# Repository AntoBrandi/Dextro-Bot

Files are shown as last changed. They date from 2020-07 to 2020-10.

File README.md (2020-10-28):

<!-- PROJECT SHIELDS -->
<!--
*** I'm using markdown "reference style" links for readability.
*** Reference links are enclosed in brackets [ ] instead of parentheses ( ).
*** See the bottom of this document for the declaration of the reference variables
*** for contributors-url, forks-url, etc. This is an optional, concise syntax you may use.
*** https://www.markdownguide.org/basic-syntax/#reference-style-links
-->
[][linkedin-url]

<!-- PROJECT LOGO -->
<br />
<p align="center">
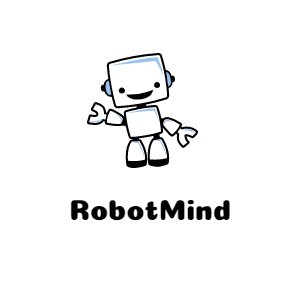
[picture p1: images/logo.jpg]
   

  <h3 align="center">DextroBot</h3>

  <p align="center">
    3D printed omni-directional robot with mechanum wheel powered by ROS
    <br />
    <a href="https://github.com/AntoBrandi/DextroBot/"><strong>Explore the docs »</strong></a>
    <br />
    <br />
    <a href="https://github.com/AntoBrandi/DextroBot/">View Demo</a>
    ·
    <a href="https://github.com/AntoBrandi/DextroBot/issues">Report Bug</a>
    ·
    <a href="https://github.com/AntoBrandi/DextroBot/issues">Request Feature</a>
  </p>
</p>

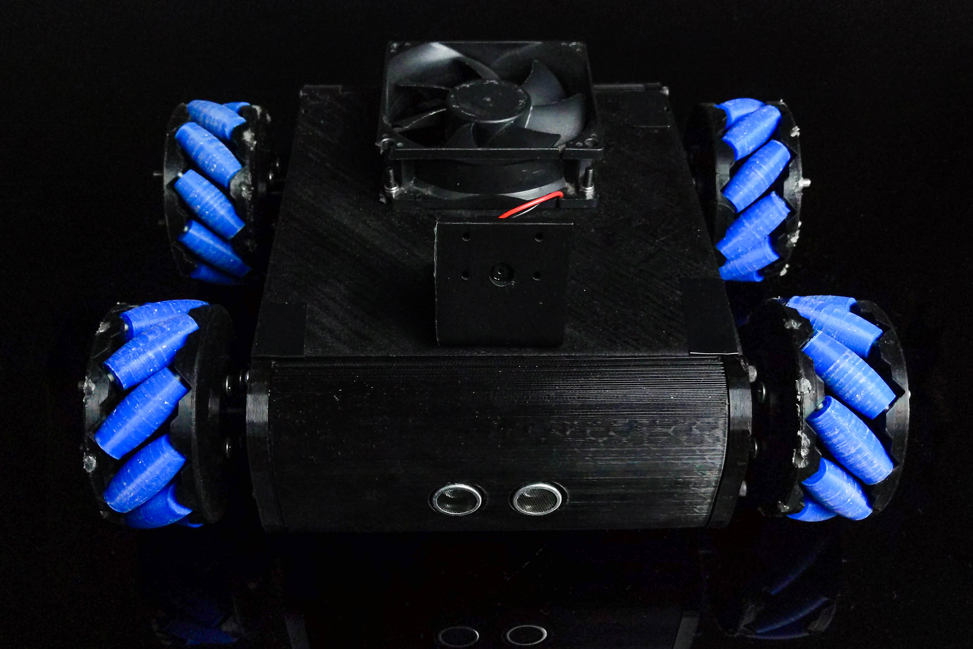
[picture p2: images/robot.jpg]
Product Name Screen Shot Real
[](https://example.com)

<!-- TABLE OF CONTENTS -->
## Table of Contents

* [About the Project](#about-the-project)
  * [Built With](#built-with)
* [Getting Started](#getting-started)
  * [Prerequisites](#prerequisites)
  * [Installation](#installation)
* [Usage](#usage)
* [Contributing](#contributing)
* [License](#license)
* [Contact](#contact)
* [Acknowledgements](#acknowledgements)

<!-- ABOUT THE PROJECT -->
## About The Project

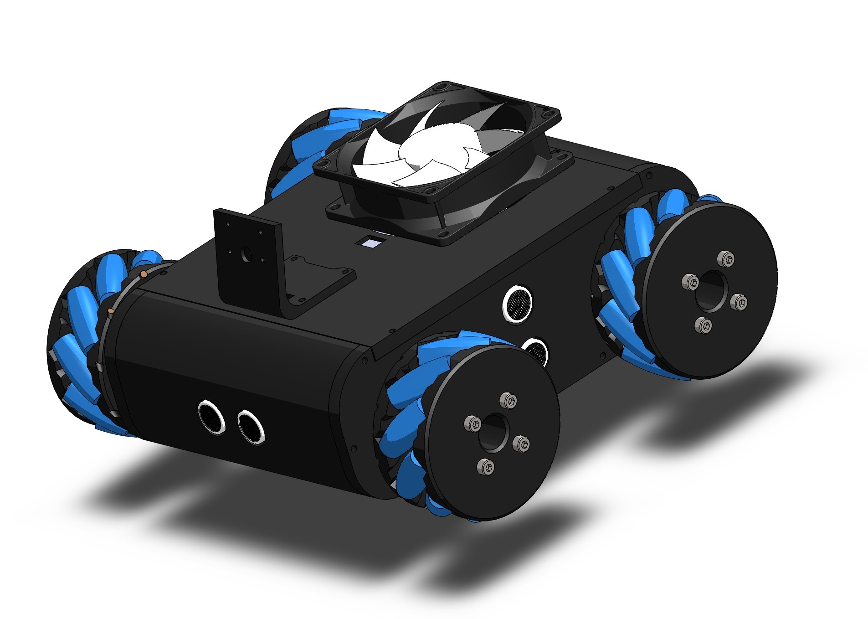
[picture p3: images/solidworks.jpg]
Product Name Screen Shot
[](https://example.com)

This project aim is to build an omni-directional robot for the indoor navigation and mapping using inexpensive sensors such as ultrasonic sensors.
Furthermore, it implements some basics human tracking and following functionalities using the raspberry pi camera mounted on its top. In order to activate or deactivate
this tracking functionalities, a speech recognition module has been implemented. This module can run on any computer with a microphone that is connected to the same Wi-Fi network 
of the robot.

### Built With
This robot is powered by:
* Raspberry Pi 4
* Arduino UNO
* CNC Shield
* Nema 17 Stepper Motor
* drv8825 Stepper Motor Driver
* 11.1V 3s LiPo Battery
* LM2596 DC-DC converter
* Raspberry Pi Camera
* HC-SR04 Ultrasonic Sensors
* MPU6050 IMU

And is controlled by:
* ROS Kinetic

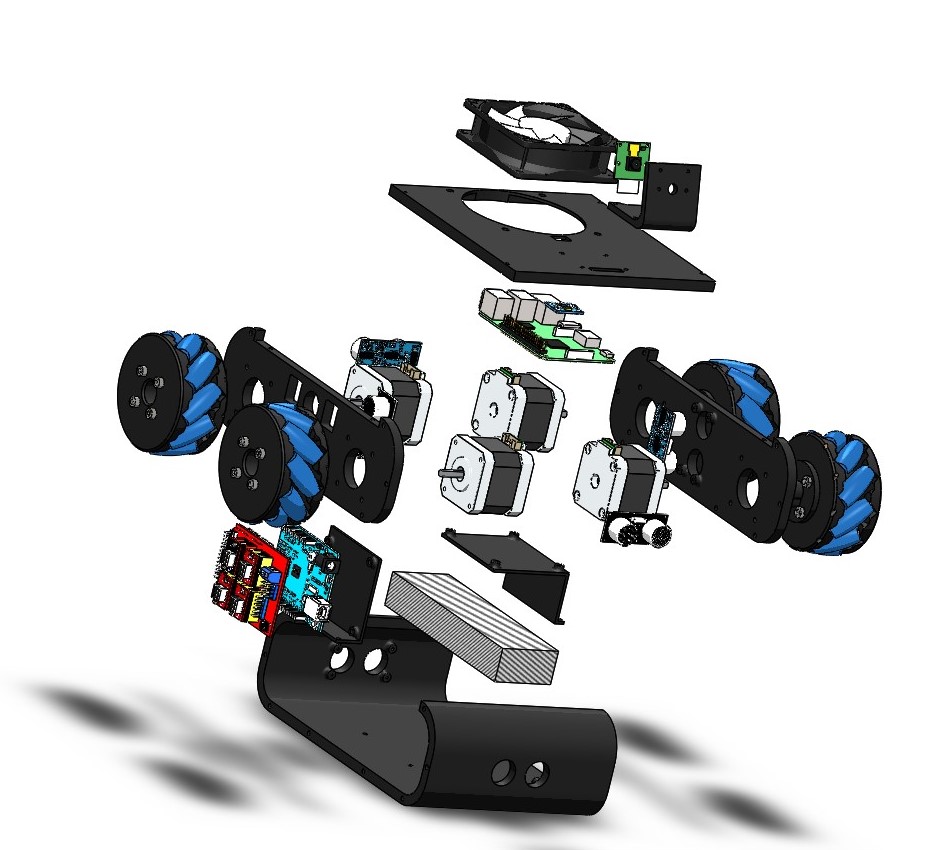
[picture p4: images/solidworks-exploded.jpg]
Product Name Screen Shot Exploded
[](https://example.com)

<!-- GETTING STARTED -->
## Getting Started

Once it's printed and assembled according and connected, there are few configuration to be made in both Raspberry Pi side and Arduino UNO.

### Prerequisites

Make sure you install correctly the following required tools before continuing
* Install Ubuntu 16.04 on Raspberry Pi 4
Use the [Ubiquity Robotics](https://downloads.ubiquityrobotics.com/pi.html) Raspberry Pi images that cames along with a lot of pre-installed functionalities such as ROS kinetic, ssh server, GPIO and camera
drivers
* Install missing ROS libraries. Some libraries that are used in this project are not in the standard ROS package. Install them with:
```sh
sudo apt-get install ros-kinetic-rosserial
```
```sh
sudo apt-get install ros-kinetic-rosserial-arduino
```
```sh
sudo apt-get install ros-kinetic-rviz-imu-plugin
```
* Install VS Code and Platform IO extension on your PC in order to build and load the Arduino code on the device

### Installation

1. Clone the repo
```sh
git clone https://github.com/AntoBrandi/DextroBot.git
```
2. Build the ROS workspace
```sh
cd ~/DextroBot/ROS/dextrobot_ws
```
```sh
catkin_make
```
3. Source the project
```sh
sudo nano ~/.bashrc
```
And add the following at the end of the document
```sh
source ~/DextroBot/ROS/dextrobot_ws/devel/setup.bash
```
4. Connect the Arduino UNO on your PC with VS Code and Platform IO. Open the [folder](https://github.com/AntoBrandi/DextroBot/tree/master/ROS/dextrobot_ws/src/dextrobot_controller/src/arduino/wheel_controller)
containing the code for the Arduino wheel control and load the main.cpp to the Arduino.

<!-- USAGE EXAMPLES -->
## Usage

To launch the ROS enviroment on the Raspberry Pi use
```sh
roslaunch dextrobot_bringup dextrobot_complete.launch view_imv:=true
```
With optional parameters
* **view_imv**: to display the motion vectors detected by the raspberry pi camera
* **launch_rviz**: to display the readings coming from the sonar sensors and the imu

<!-- CONTRIBUTING -->
## Contributing

Contributions are what make the open source community such an amazing place to be learn, inspire, and create. Any contributions you make are **greatly appreciated**.

1. Fork the Project
2. Create your Feature Branch (`git checkout -b feature/AmazingFeature`)
3. Commit your Changes (`git commit -m 'Add some AmazingFeature'`)
4. Push to the Branch (`git push origin feature/AmazingFeature`)
5. Open a Pull Request

<!-- LICENSE -->
## License

Distributed under the MIT License. See `LICENSE` for more information.

<!-- CONTACT -->
## Contact

Antonio Brandi - [LinkedIn]([linkedin-url]) - antonio.brandi@outlook.it

My Projects: [https://github.com/AntoBrandi](https://github.com/AntoBrandi)

<!-- ACKNOWLEDGEMENTS -->
## Acknowledgements
* [Ubiquity Robotics Raspberry Pi Images](https://downloads.ubiquityrobotics.com/pi.html)
* [Ubiquity Robotics raspicam_node](https://github.com/UbiquityRobotics/raspicam_node)
* [How To Mechatronics mechanum wheel](https://howtomechatronics.com/)

<!-- MARKDOWN LINKS & IMAGES -->
<!-- https://www.markdownguide.org/basic-syntax/#reference-style-links -->
[linkedin-shield]: https://img.shields.io/badge/-LinkedIn-black.svg?style=flat-square&logo=linkedin&colorB=555
[linkedin-url]: https://www.linkedin.com/in/antonio-brandi-512166bb/
[product-screenshot]: images/solidworks.jpg
[product-screenshot-exploded]: images/solidworks-exploded.jpg
[product-screenshot-real]: images/robot.jpg

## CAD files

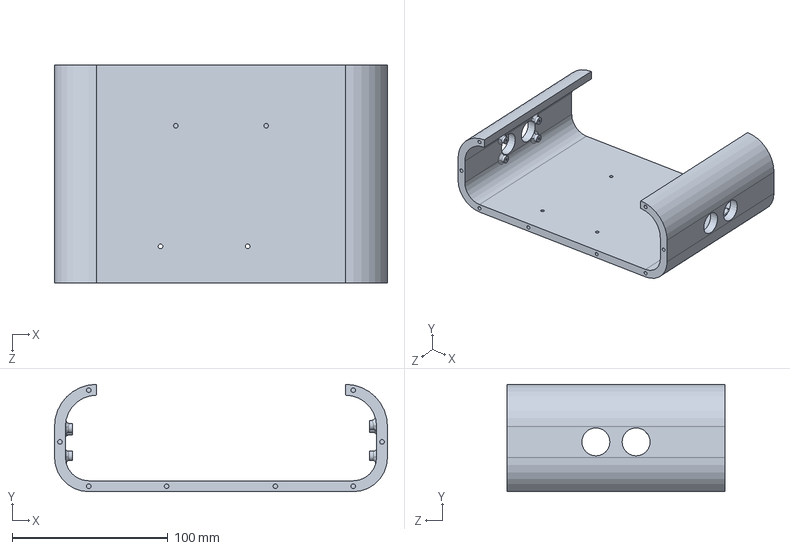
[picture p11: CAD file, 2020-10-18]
CAD/rev_2/carena_main.SLDPRT
214.0 x 69.0 x 140.0 mm

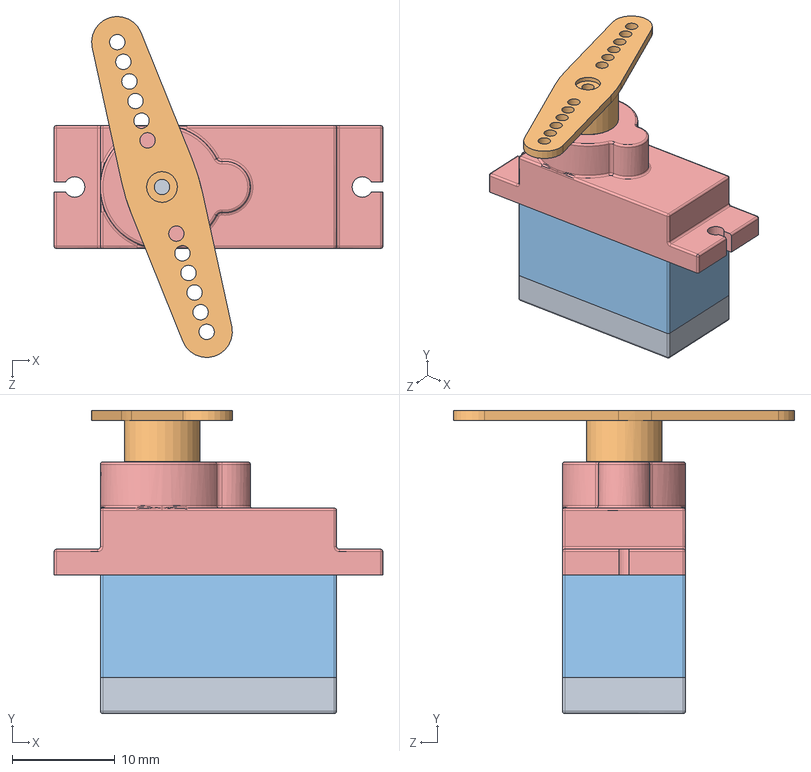
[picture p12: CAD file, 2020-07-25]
CAD/Servo/servo.SLDASM
32.0 x 29.5 x 33.2 mm
bottom
Driver
middle
screw x 4
top

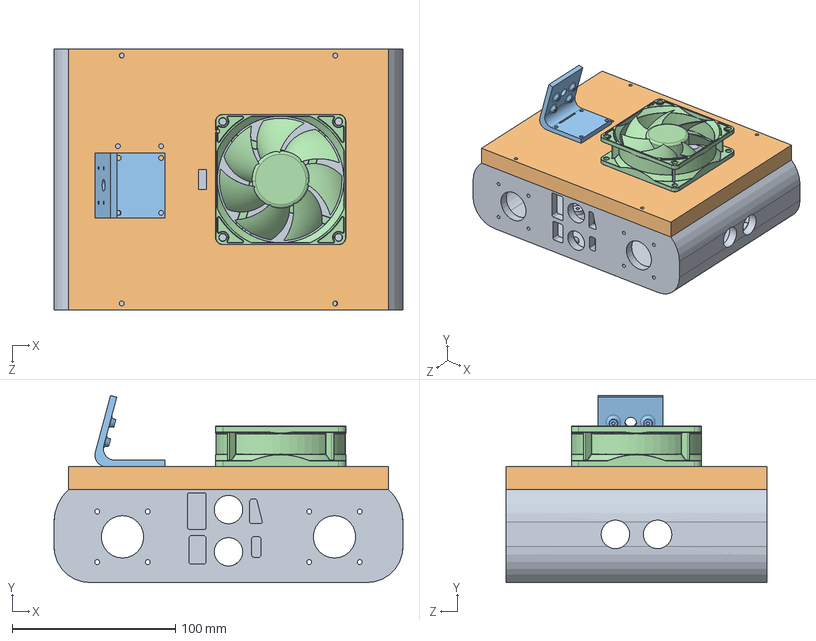
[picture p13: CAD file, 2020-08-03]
CAD/structure.SLDASM
214.0 x 114.7 x 160.0 mm
carena
carena_top_3
Camera Stand
80mm fan

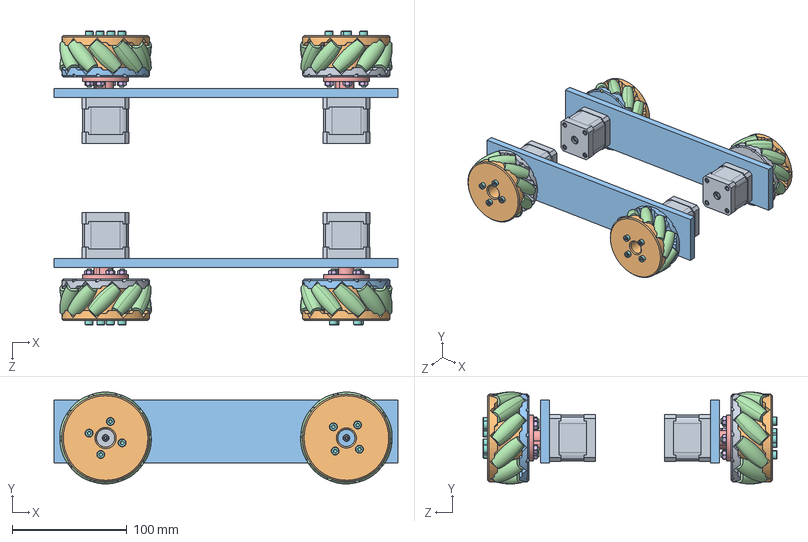
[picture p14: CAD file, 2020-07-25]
CAD/DextroBot.SLDASM
300.0 x 80.2 x 256.3 mm
NEMA 17 34mm_Varsayilan x 4
Wheel outer side Left x 2
Wheel base plate 1 Left x 2
Roller 3 x 40
Shaft Coupler Nema 17 x 4
hex nut style 1 gradeab_din_Hexagon Nut ISO 4032 - M4 - W - N x 16
Roller Shaft x 40
socket head cap screw_am_B18.3.1M - 4 x 0.7 x 45 Hex SHCS -- 20NHX x 16
Wheel base plate 1 Right x 2
Wheel outer side Right x 2
Base side plate x 2

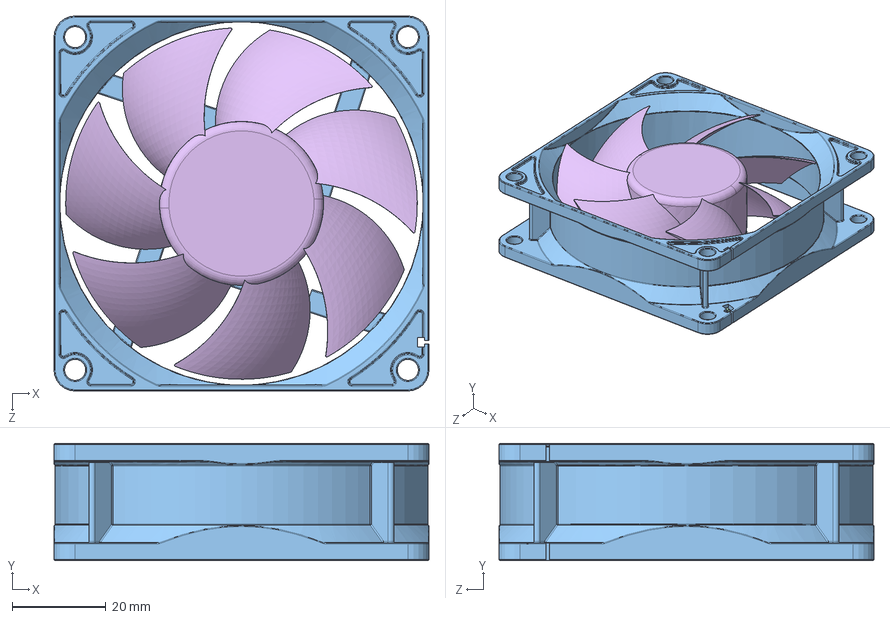
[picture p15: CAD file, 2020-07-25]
CAD/Electronics/80mm fan.SLDASM
80.0 x 25.0 x 80.0 mm
agfan
agfan-1
agfan-2
agfan-3
agfan-4
blade

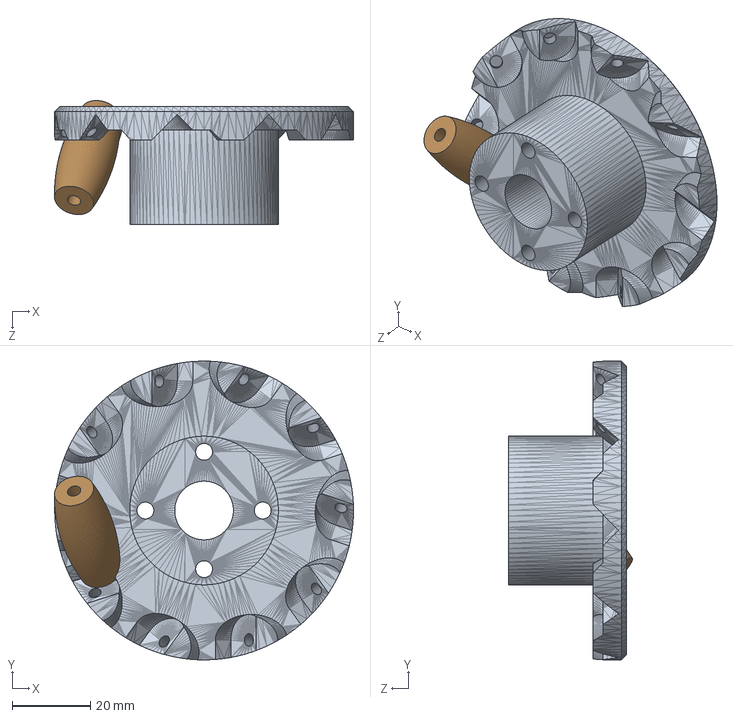
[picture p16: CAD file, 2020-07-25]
CAD/left_wheel.SLDASM
76.4 x 76.4 x 31.7 mm
Wheel outer side Left
Roller

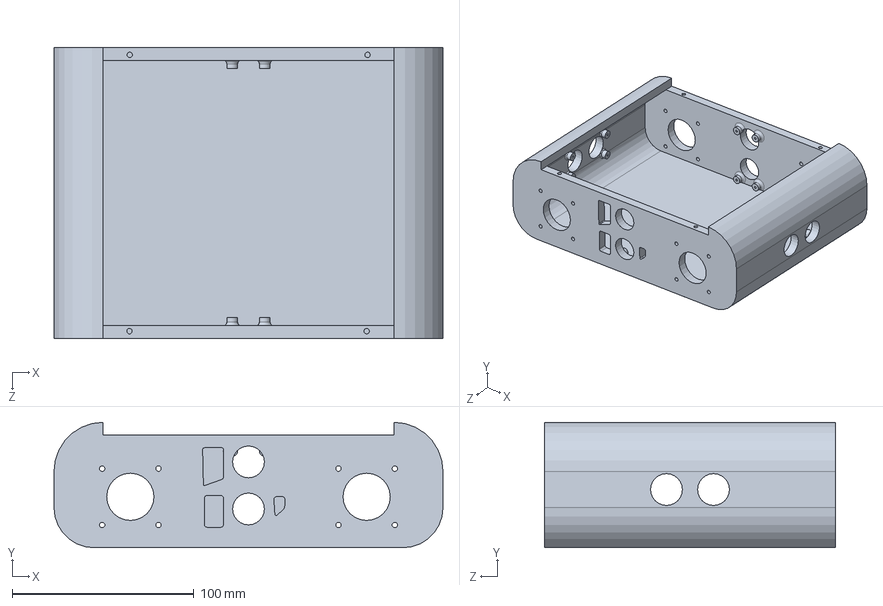
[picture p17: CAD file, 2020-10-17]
CAD/carena.SLDPRT
214.0 x 69.0 x 160.0 mm

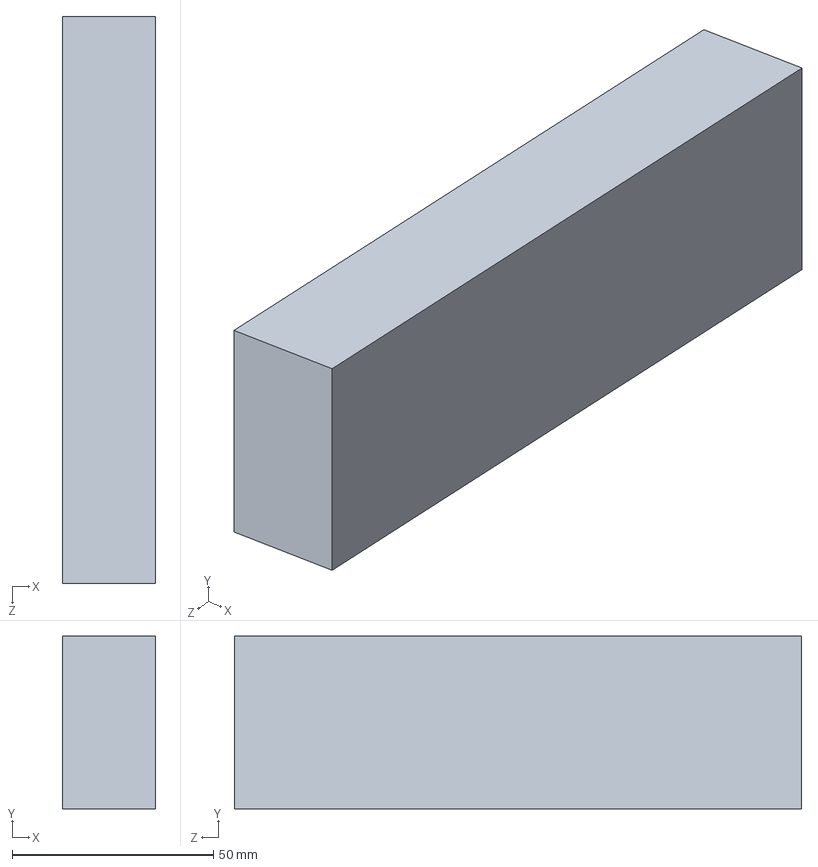
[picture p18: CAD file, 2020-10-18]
CAD/Electronics/battery.SLDPRT
23.0 x 43.0 x 141.0 mm

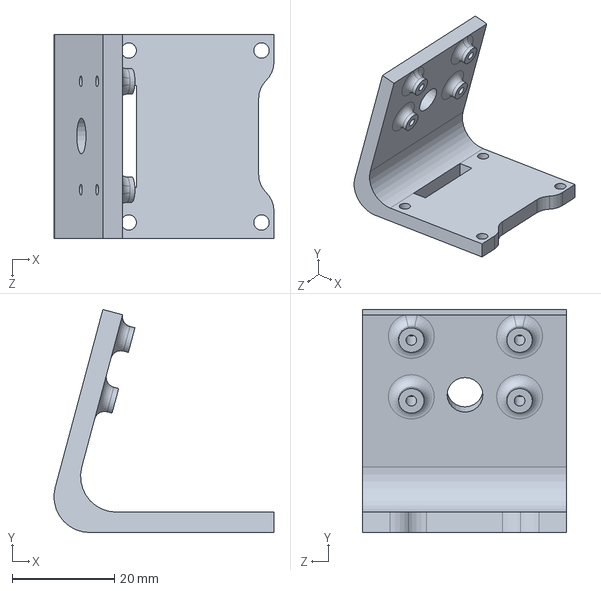
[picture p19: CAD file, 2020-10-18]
CAD/rev_2/camera_stand.SLDPRT
43.1 x 43.7 x 40.0 mm

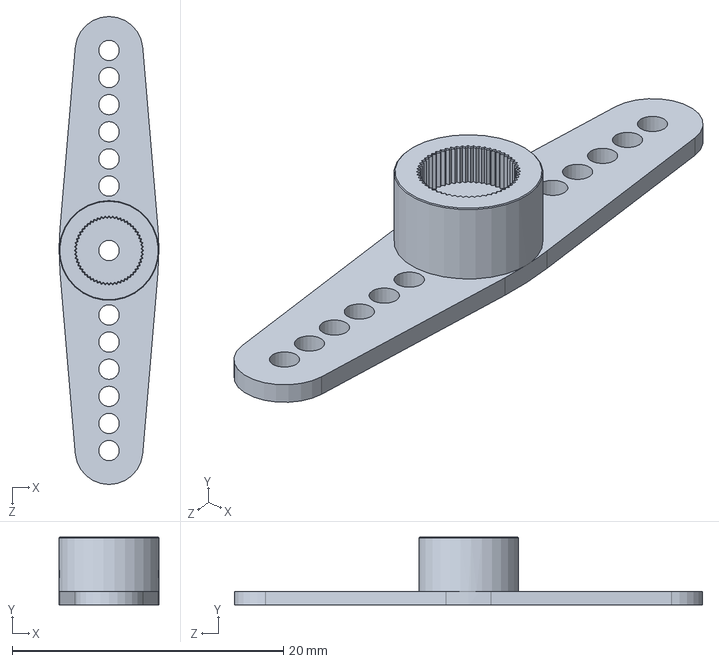
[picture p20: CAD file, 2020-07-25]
CAD/Servo/Driver.SLDPRT
7.36 x 5.00 x 34.5 mm

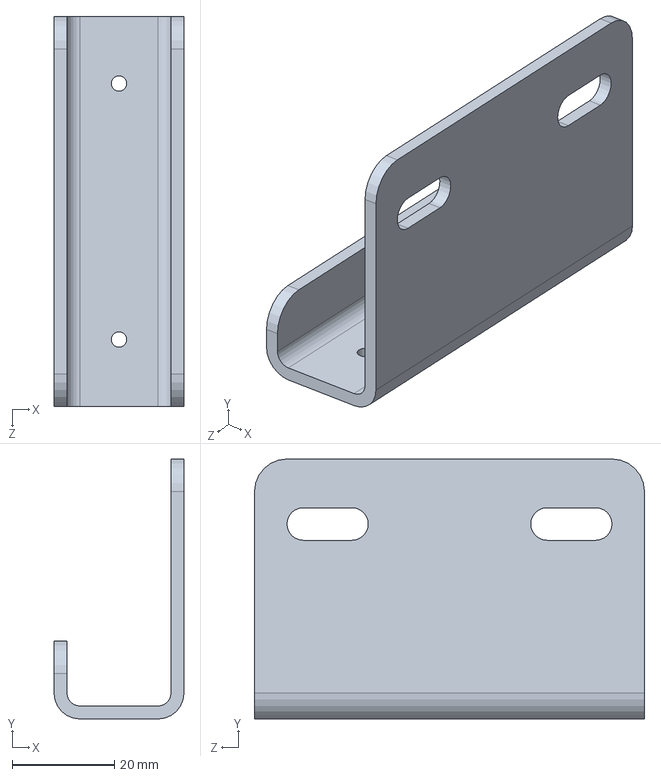
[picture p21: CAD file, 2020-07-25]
CAD/Stand/PhoneStand.SLDPRT
25.4 x 50.8 x 76.2 mm

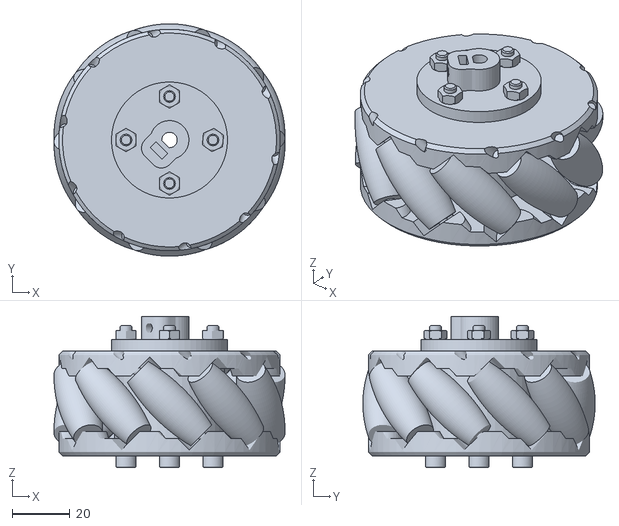
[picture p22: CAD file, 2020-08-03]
ROS/dextrobot_ws/src/dextrobot_description/src/mesh/wheels/Mecanum_Wheel_Left.STL
79.7 x 80.1 x 52.2

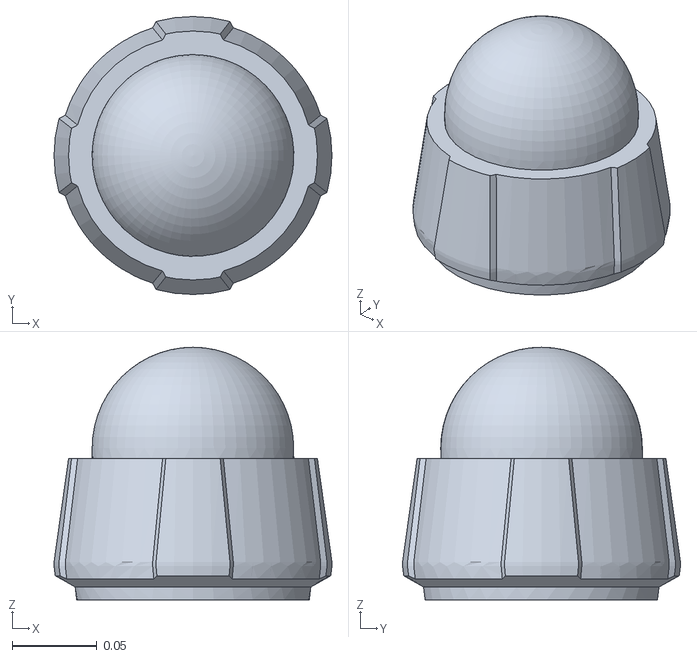
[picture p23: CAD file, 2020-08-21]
ROS/dextrobot_ws/src/robotnik_sensors/meshes/camera_axis_p5514.stl
0.164 x 0.164 x 0.149

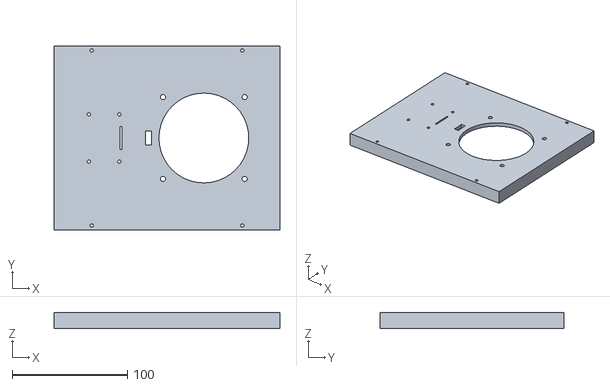
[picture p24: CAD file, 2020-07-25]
STL/carena_top_rev_2.STL
196.3 x 160.0 x 14.0

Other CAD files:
CAD/Mecanum Wheel Assembly Right.sldasm
CAD/Mecanum Wheel Assembly Left.sldasm
CAD/Electronics/Raspberry PI 3.SLDPRT
CAD/pi support 1.SLDPRT
CAD/Base plate 1.sldprt
CAD/Base side plate 2.sldprt
CAD/Base side plate.sldprt
CAD/Camera Stand v2.SLDPRT
CAD/Camera Stand.SLDPRT
CAD/Corpo2.sldprt
CAD/Corpo3.sldprt
CAD/Corpo4.sldprt
CAD/Corpo5.sldprt
CAD/Corpo6.sldprt
CAD/Electronics/5 cell LiPo battery v7.SLDPRT
CAD/Electronics/80mm fan.SLDPRT
CAD/Electronics/Arduino Uno CNC Shield V3.SLDPRT
CAD/Electronics/DRV 8825 .SLDPRT
CAD/Electronics/Female HDMI connector.SLDPRT
CAD/Electronics/FemaleUSB.SLDPRT
CAD/Electronics/MPU_6050.SLDPRT
CAD/Electronics/Nema17.SLDPRT
CAD/Electronics/Nokia 6.1 plus.SLDPRT
CAD/Electronics/RPi cam Rev 1.3.SLDPRT
CAD/Electronics/XT60_Conector.SLDPRT
CAD/Mecanum Wheel Assembly Left.SLDPRT
CAD/Mecanum Wheel Assembly Right.SLDPRT
CAD/NEMA 17 34mm_Varsayilan.sldprt
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

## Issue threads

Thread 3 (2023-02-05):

imu_sense is giving errors on i2c communication

Kolinha, 2023-02-05:
for some reason the script is giving an error with the number 121 saying remote i/o error

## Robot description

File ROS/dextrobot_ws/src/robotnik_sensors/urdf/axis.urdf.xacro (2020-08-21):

<?xml version="1.0"?>
<robot xmlns:xacro="http://wiki.ros.org/xacro" name="sensor_axis">
  <xacro:property name="ptz_joint_effort_limit" value="100.0"/>
  <xacro:property name="ptz_joint_velocity_limit" value="100.0"/>
  <xacro:property name="ptz_joint_friction" value="0.1"/>
  <xacro:property name="ptz_joint_damping" value="0.1"/>
  <xacro:property name="ptz_mechanical_reduction" value="1.0"/>
  <xacro:macro name="sensor_axis" params="prefix parent *origin far:=^|8.0 near:=^|0.05">
    <joint name="${prefix}_joint" type="fixed">
      <axis xyz="0 1 0"/>
      <xacro:insert_block name="origin"/>
      <parent link="${parent}"/>
      <child link="${prefix}_base_link"/>
    </joint>
    <link name="${prefix}_base_link">
      <inertial>
        <origin xyz="0.0 0.0 0.0" rpy="0 0 0"/>
        <mass value="0.1"/>
        <origin xyz="0 0 0" rpy="0 0 0"/>
        <inertia ixx="0.1" ixy="0" ixz="0" iyy="0.1" iyz="0" izz="0.1"/>
      </inertial>
      <visual>
        <origin xyz="0.0 0.0 0.0" rpy="0 0 0"/>
        <!-- because the origin of the mesh file is not at the "center" of the model-->
        <material name="axis_color">
          <color rgba="0.1 0.1 0.1 1"/>
        </material>
        <geometry>
          <mesh filename="package://robotnik_sensors/meshes/camera_axis_p5514.stl" scale="1.0 1.0 1.0"/>
        </geometry>
      </visual>
      <collision>
        <origin xyz="0.0 0.0 0.0" rpy="0 0 0"/>
        <!-- because the origin of the mesh file is not at the "center" of the model-->
        <geometry>
          <mesh filename="package://robotnik_sensors/meshes/camera_axis_p5514.stl" scale="1.0 1.0 1.0"/>
        </geometry>
      </collision>
    </link>
    <joint name="${prefix}_pan_joint" type="revolute">
      <axis xyz="0 0 -1"/>
      <origin xyz="0.0 0.0 0.0" rpy="0 0 0"/>
      <!-- check the displacement -->
      <parent link="${prefix}_base_link"/>
      <child link="${prefix}_pan_link"/>
      <limit effort="${ptz_joint_effort_limit}" velocity="${ptz_joint_velocity_limit}" lower="-3.1415" upper="3.1415"/>
      <joint_properties damping="${ptz_joint_damping}" friction="{ptz_joint_friction}"/>
    </joint>
    <link name="${prefix}_pan_link">
      <inertial>
        <mass value="0.1"/>
        <origin xyz="0 0 0" rpy="0 0 0"/>
        <inertia ixx="0.1" ixy="0" ixz="0" iyy="0.1" iyz="0" izz="0.1"/>
      </inertial>
    </link>
    <transmission name="${prefix}_pan_trans">
      <type>transmission_interface/SimpleTransmission</type>
      <joint name="${prefix}_pan_joint">
        <hardwareInterface>hardware_interface/VelocityJointInterface</hardwareInterface>
      </joint>
      <actuator name="pan_motor">
        <hardwareInterface>hardware_interface/VelocityJointInterface</hardwareInterface>
        <mechanicalReduction>${ptz_mechanical_reduction}</mechanicalReduction>
      </actuator>
    </transmission>
    <joint name="${prefix}_tilt_joint" type="revolute">
      <axis xyz="0 -1 0"/>
      <origin xyz="0.0 0.0 0.0"/>
      <parent link="${prefix}_pan_link"/>
      <child link="${prefix}_tilt_link"/>
      <limit effort="${ptz_joint_effort_limit}" velocity="${ptz_joint_velocity_limit}" lower="-1.5708" upper="1.5708"/>
      <joint_properties damping="${ptz_joint_damping}" friction="{ptz_joint_friction}"/>
    </joint>
    <link name="${prefix}_tilt_link">
      <inertial>
        <mass value="0.1"/>
        <origin xyz="0 0 0" rpy="0 0 0"/>
        <inertia ixx="0.1" ixy="0" ixz="0" iyy="0.1" iyz="0" izz="0.1"/>
      </inertial>
    </link>
    <transmission name="${prefix}_tilt_trans">
      <type>transmission_interface/SimpleTransmission</type>
      <joint name="${prefix}_tilt_joint">
        <hardwareInterface>hardware_interface/VelocityJointInterface</hardwareInterface>
      </joint>
      <actuator name="tilt_motor">
        <hardwareInterface>hardware_interface/VelocityJointInterface</hardwareInterface>
        <mechanicalReduction>${ptz_mechanical_reduction}</mechanicalReduction>
      </actuator>
    </transmission>
    <joint name="${prefix}_frame_joint" type="fixed">
      <origin xyz="0.0 0 0" rpy="0 0 0"/>
      <parent link="${prefix}_tilt_link"/>
      <child link="${prefix}_frame_link"/>
    </joint>
    <link name="${prefix}_frame_link">
      <inertial>
        <mass value="0.001"/>
        <origin xyz="0 0 0"/>
        <inertia ixx="0.0001" ixy="0.0" ixz="0.0" iyy="0.0001" iyz="0.0" izz="0.0001"/>
      </inertial>
    </link>
    <!-- Optical frame -->
    <joint name="${prefix}_optical_joint" type="fixed">
      <origin xyz="0 0 0" rpy="${-M_PI/2} 0 ${-M_PI/2}"/>
      <parent link="${prefix}_frame_link"/>
      <child link="${prefix}_optical_frame_link"/>
    </joint>
    <link name="${prefix}_optical_frame_link">
      <inertial>
        <mass value="0.001"/>
        <origin xyz="0 0 0"/>
        <inertia ixx="0.0001" ixy="0.0" ixz="0.0" iyy="0.0001" iyz="0.0" izz="0.0001"/>
      </inertial>
    </link>
    <gazebo reference="${prefix}_base_link">
      <material>Gazebo/FlatBlack</material>
    </gazebo>
    <!-- Axis sensor for simulation -->
    <sensor_axis_gazebo/>
  </xacro:macro>




  <xacro:macro name="sensor_axis_gazebo">
    <gazebo reference="${prefix}_frame_link">
      <sensor type="camera" name="${prefix}_sensor">
        <update_rate>30.0</update_rate>
        <camera>
          <horizontal_fov>${60.0*M_PI/180.0}</horizontal_fov>
          <image>
            <format>R8G8B8</format>
            <width>640</width>
            <height>480</height>
          </image>
          <clip>
            <near>${near}</near>
            <far>${far}</far>
          </clip>
        </camera>
        <plugin name="${prefix}_controller" filename="libgazebo_ros_camera.so">
          <alwaysOn>true</alwaysOn>
          <updateRate>0.0</updateRate>
          <cameraName>${prefix}</cameraName>
          <imageTopicName>image_raw</imageTopicName>
          <cameraInfoTopicName>camera_info</cameraInfoTopicName>
          <frameName>/${prefix}_optical_frame_link</frameName>
          <hackBaseline>0.0</hackBaseline>
          <distortionK1>0.0</distortionK1>
          <distortionK2>0.0</distortionK2>
          <distortionK3>0.0</distortionK3>
          <distortionT1>0.0</distortionT1>
          <distortionT2>0.0</distortionT2>
        </plugin>
      </sensor>
    </gazebo>
  </xacro:macro>

</robot>

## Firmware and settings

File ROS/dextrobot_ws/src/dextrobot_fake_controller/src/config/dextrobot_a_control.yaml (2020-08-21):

  joint_pan_position_controller:
    type: velocity_controllers/JointPositionController
    joint: dextrobot_a_front_ptz_camera_pan_joint
    pid: {p: 100.0, i: 0.01, d: 10.0}

  joint_tilt_position_controller:
    type: velocity_controllers/JointPositionController
    joint: dextrobot_a_front_ptz_camera_tilt_joint
    pid: {p: 100.0, i: 0.01, d: 10.0}

  robotnik_base_control:
    type        : "diff_drive_controller/DiffDriveController"
    left_wheel  : ['dextrobot_a_front_left_wheel_joint','dextrobot_a_back_left_wheel_joint']
    right_wheel : ['dextrobot_a_front_right_wheel_joint','dextrobot_a_back_right_wheel_joint']
    publish_rate: 50.0
    pose_covariance_diagonal : [0.001, 0.001, 1000000.0, 1000000.0, 1000000.0, 1000.0]
    twist_covariance_diagonal: [0.001, 0.001, 1000000.0, 1000000.0, 1000000.0, 1000.0]

    # Wheel separation and diameter. These are both optional.
    # diff_drive_controller will attempt to read either one or both from the
    # URDF if not specified as a parameter
    wheel_separation : 0.543 #def 0.433
    wheel_radius : 0.110 #def 0.0762

    # Wheel separation and radius multipliers
    wheel_separation_multiplier: 1.0 # default: 1.0
    wheel_radius_multiplier    : 1.0 # default: 1.0

    # Velocity commands timeout [s], default 0.5
    cmd_vel_timeout: 0.25

    # Base frame_id
    base_frame_id: dextrobot_a_base_footprint
    odom_frame_id: dextrobot_a_odom
    enable_odom_tf: true

    # Velocity and acceleration limits
    # Whenever a min_* is unspecified, default to -max_*
    linear:
      x:
        has_velocity_limits    : true
        max_velocity           : 3.0 #1.5 # m/s
        min_velocity           : -3.0 #-1.5 # m/s
        has_acceleration_limits: true
        max_acceleration       : 6.0 #3.00  # m/s^2
        min_acceleration       : -6.0 #-3.00 # m/s^2
    angular:
      z:
        has_velocity_limits    : true
        max_velocity           : 6.0 #3.0  # rad/s
        has_acceleration_limits: true
        max_acceleration       : 6.0 #3.0  # rad/s^2


  joint_read_state_controller:
    type: joint_state_controller/JointStateController
    publish_rate: 100.0

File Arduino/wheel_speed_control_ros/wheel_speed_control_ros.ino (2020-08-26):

#include <AccelStepper.h>
#include <ros.h>
#include <std_msgs/String.h>

// Define the PIN number of the Arduino board connected with the driver motors
// MOTOR 1
#define dirPin_1 5
#define stepPin_1 2
// MOTOR 2
#define dirPin_2 6
#define stepPin_2 3
// MOTOR 3
#define dirPin_3 7
#define stepPin_3 4
// MOTOR 4
#define dirPin_4 13
#define stepPin_4 12
// AccelStepper parameter
#define motorInterfaceType 1
#define enable_shield 8

// Stepper Motor control parameters
// Max speed of the steppers in steps per second
#define MAX_SPEED 1500
// Max acceleration of the steppers in steps per second ^2
#define MAX_ACCELERATION 1000
// Speed levels for the robot mouvements
#define SUPERSONIC 1500
#define INSANE 1000
#define SUPERFAST 800
#define FAST 600
#define NORMAL 400
#define SLOW 300

// Track the current action on the stepper
int action = 0;

// Function that is called once a message is published on the topic on which this Arduino is subscribed
void trigger(const std_msgs::String& msg){
  String ms = msg.data;
  // for debug
  if((ms == "A") || (ms == "a")){
    action = 1;
  }
  else if ((ms == "Q") || (ms == "q")){
    action = 0;
  }
}

// Create an instance of the class AccelStepper for each stepper motor connected to the Arduino board
// via DRV8825 stepper driver
AccelStepper motor_1 = AccelStepper(motorInterfaceType, stepPin_1, dirPin_1);
AccelStepper motor_2 = AccelStepper(motorInterfaceType, stepPin_2, dirPin_2);
AccelStepper motor_3 = AccelStepper(motorInterfaceType, stepPin_3, dirPin_3);
AccelStepper motor_4 = AccelStepper(motorInterfaceType, stepPin_4, dirPin_4);

// Set this Arduino controller to be a ROS Node that can publish and subscribe to ROS topics
ros::NodeHandle nh;
ros::Subscriber<std_msgs::String> sub("/stepper_trigger", trigger );

void setup() {
  // Enable the CNC shield
    pinMode(enable_shield, OUTPUT);
    digitalWrite(enable_shield, LOW);
  
  // Set the maximum speed 
  motor_1.setMaxSpeed(MAX_SPEED);
  motor_2.setMaxSpeed(MAX_SPEED);
  motor_3.setMaxSpeed(MAX_SPEED);
  motor_4.setMaxSpeed(MAX_SPEED);

  // Set the maximum acceleration
  motor_1.setAcceleration(MAX_ACCELERATION);
  motor_2.setAcceleration(MAX_ACCELERATION);
  motor_3.setAcceleration(MAX_ACCELERATION);
  motor_4.setAcceleration(MAX_ACCELERATION);

  // cerate and initialize a ROS node on this Arduino controller
  nh.initNode();
  nh.subscribe(sub);
}
void loop() {
  // According to the last received message control the stepper
  switch(action){
    case 0:
      stopRobot();
      break;
    case 1:
      goForward(NORMAL);
      break;
    default:
      stopRobot();
      break;
  }
  
  // Keep ROS Node Up & Running
  nh.spinOnce();
}


// Omnidirectional wheels mouvements
// SPEED CONTROL
void goForward(int velocity){
  // Set the speed in steps per second:
  motor_1.setSpeed(velocity);
  motor_2.setSpeed(velocity);
  motor_3.setSpeed(velocity);
  motor_4.setSpeed(velocity);
  // Step the motor with a constant speed as set by setSpeed():
  motor_1.runSpeed();
  motor_2.runSpeed();
  motor_3.runSpeed();
  motor_4.runSpeed();  
}

void goBackward(int velocity){
  // Set the speed in steps per second:
  motor_1.setSpeed(-velocity);
  motor_2.setSpeed(-velocity);
  motor_3.setSpeed(-velocity);
  motor_4.setSpeed(-velocity);
  // Step the motor with a constant speed as set by setSpeed():
  motor_1.runSpeed();
  motor_2.runSpeed();
  motor_3.runSpeed();
  motor_4.runSpeed();
}

void goRight(int velocity){
  // Set the speed in steps per second:
  motor_1.setSpeed(velocity);
  motor_2.setSpeed(-velocity);
  motor_3.setSpeed(-velocity);
  motor_4.setSpeed(velocity);
  // Step the motor with a constant speed as set by setSpeed():
  motor_1.runSpeed();
  motor_2.runSpeed();
  motor_3.runSpeed();
  motor_4.runSpeed();
}

void goLeft(int velocity){
  // Set the speed in steps per second:
  motor_1.setSpeed(-velocity);
  motor_2.setSpeed(velocity);
  motor_3.setSpeed(velocity);
  motor_4.setSpeed(-velocity);
  // Step the motor with a constant speed as set by setSpeed():
  motor_1.runSpeed();
  motor_2.runSpeed();
  motor_3.runSpeed();
  motor_4.runSpeed();
}

void goForwardRight(int velocity){
  // Set the speed in steps per second:
  motor_1.setSpeed(velocity);
  motor_2.setSpeed(0);
  motor_3.setSpeed(0);
  motor_4.setSpeed(velocity);
  // Step the motor with a constant speed as set by setSpeed():
  motor_1.runSpeed();
  motor_2.runSpeed();
  motor_3.runSpeed();
  motor_4.runSpeed();
}

void goForwardLet(int velocity){
  // Set the speed in steps per second:
  motor_1.setSpeed(0);
  motor_2.setSpeed(velocity);
  motor_3.setSpeed(velocity);
  motor_4.setSpeed(0);
  // Step the motor with a constant speed as set by setSpeed():
  motor_1.runSpeed();
  motor_2.runSpeed();
  motor_3.runSpeed();
  motor_4.runSpeed();
}

void goBackwardRight(int velocity){
  // Set the speed in steps per second:
  motor_1.setSpeed(0);
  motor_2.setSpeed(-velocity);
  motor_3.setSpeed(-velocity);
  motor_4.setSpeed(0);
  // Step the motor with a constant speed as set by setSpeed():
  motor_1.runSpeed();
  motor_2.runSpeed();
  motor_3.runSpeed();
  motor_4.runSpeed();
}

void goBackwardLeft(int velocity){
  // Set the speed in steps per second:
  motor_1.setSpeed(-velocity);
  motor_2.setSpeed(0);
  motor_3.setSpeed(0);
  motor_4.setSpeed(-velocity);
  // Step the motor with a constant speed as set by setSpeed():
  motor_1.runSpeed();
  motor_2.runSpeed();
  motor_3.runSpeed();
  motor_4.runSpeed();
}

// POSITION CONTROL
void moveRobotTo(int steps_1, int steps_2, int steps_3, int steps_4){
  // set a target position in steps for each motor
  motor_1.moveTo(steps_1);
  motor_2.moveTo(steps_2);
  motor_3.moveTo(steps_3);
  motor_4.moveTo(steps_4);
  // Reach the position goal
  motor_1.runToPosition();
  motor_2.runToPosition();
  motor_3.runToPosition();
  motor_4.runToPosition();
}

// Stop all the motors
void stopRobot(){
  // Set the speed in steps per second:
  motor_1.setSpeed(0);
  motor_2.setSpeed(0);
  motor_3.setSpeed(0);
  motor_4.setSpeed(0);
  // Step the motor with a constant speed as set by setSpeed():
  motor_1.runSpeed();
  motor_2.runSpeed();
  motor_3.runSpeed();
  motor_4.runSpeed();
}

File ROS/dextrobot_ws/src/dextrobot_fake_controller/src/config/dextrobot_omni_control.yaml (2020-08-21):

joint_blw_velocity_controller:
  type: velocity_controllers/JointVelocityController
  joint: dextrobot_back_left_wheel_joint
joint_brw_velocity_controller:
  type: velocity_controllers/JointVelocityController
  joint: dextrobot_back_right_wheel_joint
joint_frw_velocity_controller:
  type: velocity_controllers/JointVelocityController
  joint: dextrobot_front_right_wheel_joint
joint_flw_velocity_controller:
  type: velocity_controllers/JointVelocityController
  joint: dextrobot_front_left_wheel_joint

robotnik_base_control:
  type: dextrobot_controller/SummitXLController
  joint:
    front_right_wheel_joint:
      name: dextrobot_front_right_wheel_joint
      max_speed: 27.27 # rad/s
    front_left_wheel_joint:
      name: dextrobot_front_left_wheel_joint
      max_speed: 27.27 # rad/s
    back_right_wheel_joint:
      name: dextrobot_back_right_wheel_joint
      max_speed: 27.27 # rad/s
    back_left_wheel_joint:
      name: dextrobot_back_left_wheel_joint
      max_speed: 27.27 # rad/s
  linear_speed_limit: 1.5 # m/s
  linear_acceleration_limit: 3 # m/s^2
  angular_speed_limit: 3 # rad/s
  angular_acceleration_limit: 3 # rad/s^2
  odom_frame: dextrobot_odom
  robot_base_frame: dextrobot_base_footprint
  odom_broadcast_tf: true
  odom_topic: 'robotnik_base_control/odom'
  wheel_base: 0.458
  track_width: 0.462
  wheel_diameter: 0.25
  cmd_watchdog_duration: 0.2
  imu_watchdog_duration: 0.1
  imu_topic: imu/data
  odom_publish_frequency: 100
  cmd_vel        : 'robotnik_base_control/cmd_vel'
  kinematic_mode : 'omni'
  motion_odometry: true
  in_motion_timer: 2.0

joint_read_state_controller:
  type: joint_state_controller/JointStateController 
  publish_rate: 100.0

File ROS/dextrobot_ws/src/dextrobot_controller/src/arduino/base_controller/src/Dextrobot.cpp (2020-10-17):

/*
  Dextrobot.cpp - DextroBot
  Class that cointains the implementation of the low level omnidirectional mouvements
  for the robot based on the willing direction of the mouvement the stepper motors are controlled
  differently and independently in order to achieve the desired mouvement.
  Copyright (c) 2020 Antonio Brandi.  All right reserved.
*/

#include "Dextrobot.h"

Dextrobot::Dextrobot(/* args */)
{
    // Enable the CNC shield
    pinMode(ENABLE_SHIELD, OUTPUT);
    digitalWrite(ENABLE_SHIELD, LOW);
}

Dextrobot::~Dextrobot()
{
}

void Dextrobot::goForward(float velocity){
  // Set the speed in steps per second:
  motor_1.setSpeed(velocity);
  motor_2.setSpeed(-velocity);
  motor_3.setSpeed(velocity);
  motor_4.setSpeed(-velocity);
}

void Dextrobot::goBackward(float velocity){
    // Set the speed in steps per second:
    motor_1.setSpeed(-velocity);
    motor_2.setSpeed(velocity);
    motor_3.setSpeed(-velocity);
    motor_4.setSpeed(velocity);
}

void Dextrobot::goRight(float velocity){
    // Set the speed in steps per second:
    motor_1.setSpeed(velocity);
    motor_2.setSpeed(velocity);
    motor_3.setSpeed(-velocity);
    motor_4.setSpeed(-velocity);
}

void Dextrobot::goLeft(float velocity){
    // Set the speed in steps per second:
    motor_1.setSpeed(-velocity);
    motor_2.setSpeed(-velocity);
    motor_3.setSpeed(velocity);
    motor_4.setSpeed(velocity);
}

void Dextrobot::goForwardRight(float velocity){
    // Set the speed in steps per second:
    motor_1.setSpeed(velocity);
    motor_2.setSpeed(0);
    motor_3.setSpeed(0);
    motor_4.setSpeed(-velocity);
}

void Dextrobot::goForwardLeft(float velocity){
    // Set the speed in steps per second:
    motor_1.setSpeed(0);
    motor_2.setSpeed(-velocity);
    motor_3.setSpeed(velocity);
    motor_4.setSpeed(0);
}

void Dextrobot::goBackwardRight(float velocity){
    // Set the speed in steps per second:
    motor_1.setSpeed(0);
    motor_2.setSpeed(velocity);
    motor_3.setSpeed(-velocity);
    motor_4.setSpeed(0);
}

void Dextrobot::goBackwardLeft(float velocity){
    // Set the speed in steps per second:
    motor_1.setSpeed(-velocity);
    motor_2.setSpeed(0);
    motor_3.setSpeed(0);
    motor_4.setSpeed(velocity);
}

void Dextrobot::rotateClockwise(float velocity){
    // Set the speed in steps per second:
    motor_1.setSpeed(velocity);
    motor_2.setSpeed(velocity);
    motor_3.setSpeed(velocity);
    motor_4.setSpeed(velocity);
}

void Dextrobot::rotateCounterClockwise(float velocity){
    // Set the speed in steps per second:
    motor_1.setSpeed(-velocity);
    motor_2.setSpeed(-velocity);
    motor_3.setSpeed(-velocity);
    motor_4.setSpeed(-velocity);
}

void Dextrobot::stop(){
    // Set the speed in steps per second:
    motor_1.setSpeed(0);
    motor_2.setSpeed(0);
    motor_3.setSpeed(0);
    motor_4.setSpeed(0);
}

// Update the reading of each sensor
void Dextrobot::sense(){
    imu.sense();
    sonar_1.sense();
    sonar_2.sense();
    sonar_3.sense();
    sonar_4.sense();
}

// Run the motors
void Dextrobot::run(){
    // Step the motor with a constant speed as set by setSpeed():
    motor_1.runSpeed();
    motor_2.runSpeed();
    motor_3.runSpeed();
    motor_4.runSpeed();
}

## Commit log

2016-02-11 all the sensors are publishing on ros
2016-02-11 added camera library
2020-07-27 linking the arduino script with ros
2020-07-30 ROS controlled stepper motor interreting ROS messages from Arduino
2020-08-01 init of the Arduino node that will receive cmd_vel messages and consequently move the robot
2020-08-01 code tested and working the bidirectional communication between ROS and Arduino. Now Arduino is ready to convert the cmd_vel messages in mouvements for the robot
2020-08-03 urdf and meshes structure
    [dextrobot.urdf.xacro, omni_wheel.urdf.xacro]
2020-08-03 added stl file for urdf meshes
    [80mm fan.SLDPRT, Mecanum Wheel Assembly Left.SLDPRT, Mecanum Wheel Assembly Right.SLDPRT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]
2020-08-03 added COLLADA files to the meshes
    [Mecanum_Wheel_Left.STL, Mecanum_Wheel_Right.STL]
2020-08-03 creation of the urdf description files for the dextrobot
    [dextrobot.urdf.xacro, dextrobot_base.urdf.xacro, omni_wheel.urdf.xacro]
2020-08-03 added rviz launch file
    [dextrobot_base.gazebo.xacro]
2020-08-03 small changes to make the launch file work
    [dextrobot.urdf.xacro, dextrobot_base.urdf.xacro]
2020-08-03 added sonar sensor publisher node on Arduino
2020-08-03 minor changes for debugging the ultrasonic range publisher
2020-08-03 created an IMU message publisher from Arduino over ROS
2020-08-04 working version of the imu publisher
2020-08-04 added python subscriber and converter to imu data
2020-08-04 python imu message composer
2020-08-04 first working version of the python imu reader and converter
2020-08-04 conversion of the IMU data in RPY coordinates
2020-08-04 created a launch file for the IMU visualization
2020-08-04 finalization of the arduino range publisher
2020-08-05 added robot description and visualization in RVIZ
    [dextrobot.urdf.xacro, dextrobot_base.gazebo.xacro, dextrobot_base.urdf.xacro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]
2020-08-05 tf parameters tuning
    [dextrobot.urdf.xacro, dextrobot_base.urdf.xacro, omni_wheel.urdf.xacro]
2020-08-05 uniform the unit of measurement
    [dextrobot.urdf.xacro, dextrobot_base.urdf.xacro, omni_wheel.urdf.xacro]
2020-08-11 integraed the IMU reader and publisher into the main script
2020-08-12 added all the classes for the sensors and actuators of the robot
2020-08-12 first version for publishing all the sensor data
2020-08-13 update for the gitignore file
    [Camera.cfg]
2020-08-13 added easy launch file for the visualization of the pi camera images
    [Camera Stand v2.SLDPRT, Camera Stand v2.STL]
2020-08-17 integration with the arduino mega and the cnc shield
    [pi support 1.SLDPRT, pi support 1.STL, pi support 2.SLDPRT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]
2020-08-19 changed the upload protocol for the fake arduino mega
2020-08-20 added robotnik sensor lib
    [all_sensors.urdf.xacro, antenna_3GO16.stl, asus_xtion_pro.urdf.xacro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]
2020-08-20 added resources for the gazebo simulation
    [dextrobot_a_control.yaml, dextrobot_b_control.yaml, dextrobot_c_control.yaml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]
2020-08-21 adjusted ultrasonic sensor publisher
2020-08-21 solved the problem of the IMU that was not able to publish data
    [Dextrobot.cpp, Dextrobot.h, main.cpp]
2020-08-21 edited the launch file for the arduino mega
2020-08-26 changes to the sonar logic in order to make the readings based on events
2020-08-28 imu stable version
2020-08-29 speeded a bit up inserting a delay between two imu readings
2020-08-29 best result possible removing the unused sonar
2020-08-29 works fine also at higher frequency of imu and sonar scans, the problem was the missing sonar
2020-08-29 added the message converter for the sensor readings coming from arduino
2020-08-29 implementation of all the modules that enable the communication and the conversion between ros and arduino
2020-08-29 added frames for sonar and imu sensor
    [dextrobot.urdf.xacro, dextrobot_base.urdf.xacro]
2020-08-29 complete visualization of the robot with the real sensors
2020-09-02 added last sonar sensor
2020-09-02 update the range messages so that they are referred to the correct frame
    [sonar_raw_subscriber.py]
2020-09-04 trying to speed up the publish code by alternate the sonar that can publish the message
2020-09-04 solved problem on the yaw of the imu
    [Dextrobot.h]
2020-09-05 all sensors version on ros kinetic
2020-09-07 new code version in order to control only the wheel with the arduino mega
2020-09-07 added simplified controller for the arduino mega that manages only the imu and the wheels
2020-09-07 added sensing function to the raspberry pi
2020-09-20 edit the script in order to work with the arduino uno and the android app for the control
    [Arduino Uno CNC Shield V3.SLDPRT, MPU_6050.SLDPRT, Raspberry PI 3.SLDPRT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]
2020-09-20 wrong python or statement
    [imu_sense.py]
2020-09-20 roll and pitch working version
2020-09-20 tuned parameters for the yaw
2020-09-22 working version of the sonar range sense function via raspberry
2020-10-02 mouvement tracking via imv
    [battery_cover.SLDPRT, battery_cover_2.SLDPRT, battery_cover_2.STL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]
2020-10-03 adjusted motor direction mouvements
2020-10-03 added speech recognition functionalities that enables robot functions
    [carena_top.SLDPRT, carena_top.STL]
2020-10-18 edited thresholds
    [80mm fan.SLDPRT, battery.SLDPRT, battery_cover_2.SLDPRT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]
